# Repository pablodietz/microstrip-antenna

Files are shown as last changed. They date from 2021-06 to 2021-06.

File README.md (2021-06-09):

<p align="center">
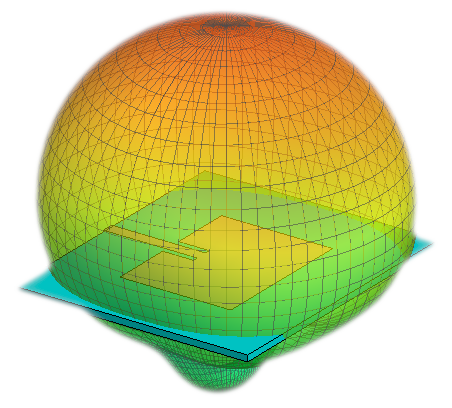
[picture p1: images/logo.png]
  
</p>

# Microstrip Antenna
Design and implementation of microstrip antenna. The idea is to improve the connectivity of a home WIFI link for G and N standards.

## Specs

* Resonance Frequency (fr): 2.422 GHz
* SWR < 2 with BW > 44 MHz
* Directivity > 3dB

## Substrate

* Material: FR4
* Substrate height (h): 1.6 mm
* Relative dielectric constant of substrate: 4.5
* Loss tangent: 0.0025

## Dimensions

<p align="center">
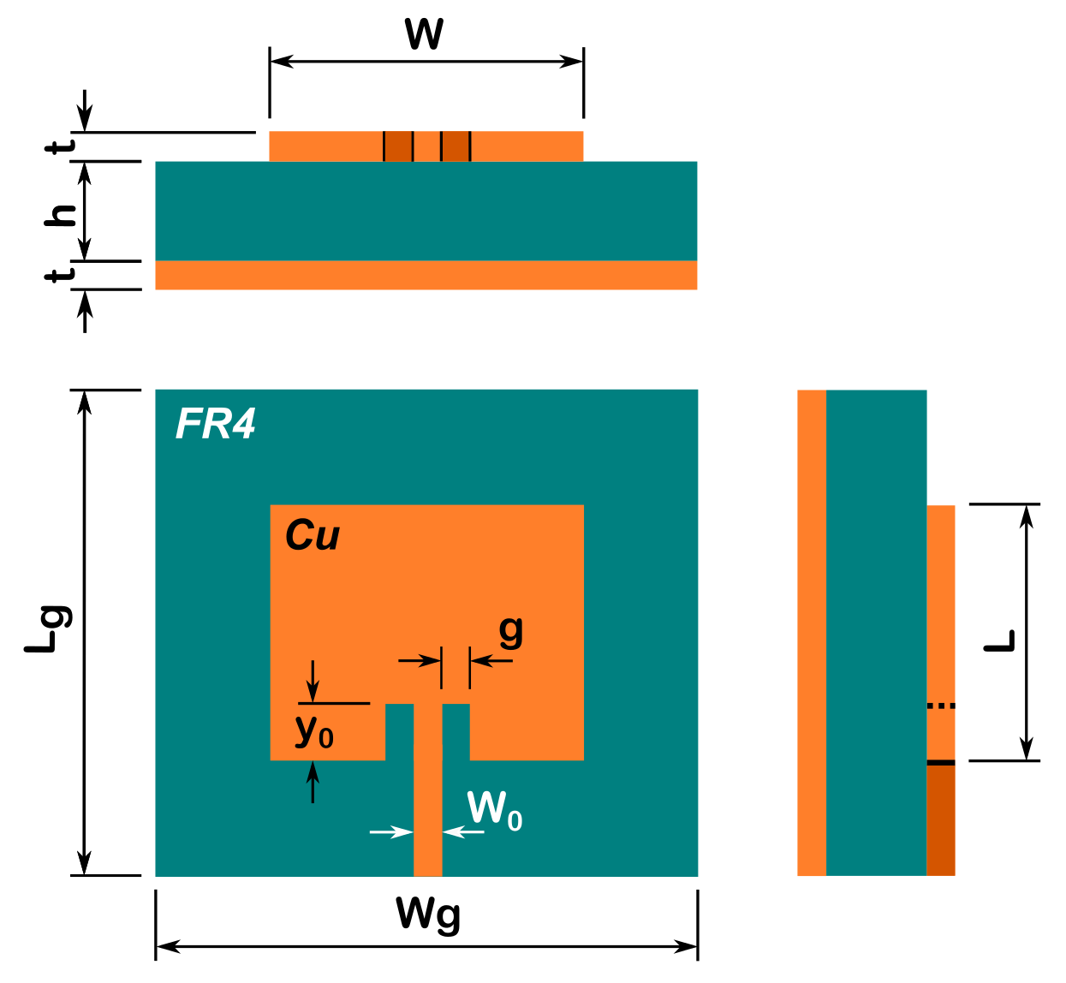
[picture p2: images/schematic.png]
  
</p>

<table align="center">
  <tr>
    <th align="center">Dimension</th>
    <th align="center">Value</th>
    <th align="center">Unit</th>
  </tr>
  <tr>
    <td align="center">t</td>
    <td align="center">35</td>
    <td align="center">µm</td>
  </tr>
  <tr>
    <td align="center">h</td>
    <td align="center">1.6</td>
    <td align="center">mm</td>
  </tr>
  <tr>
    <td align="center">W</td>
    <td align="center">37.35</td>
    <td align="center">mm</td>
  </tr>
  <tr>
    <td align="center">L</td>
    <td align="center">28.55</td>
    <td align="center">mm</td>
  </tr>
  <tr>
    <td align="center">Wg</td>
    <td align="center">70</td>
    <td align="center">mm</td>
  </tr>
  <tr>
    <td align="center">Lg</td>
    <td align="center">60</td>
    <td align="center">mm</td>
  </tr>
  <tr>
    <td align="center">W0</td>
    <td align="center">3.05</td>
    <td align="center">mm</td>
  </tr>
  <tr>
    <td align="center">g</td>
    <td align="center">1.4</td>
    <td align="center">mm</td>
  </tr>
  <tr>
    <td align="center">y0</td>
    <td align="center">7.94</td>
    <td align="center">mm</td>
  </tr>
</table>

## Layout and Finished Antenna

<p align="center">
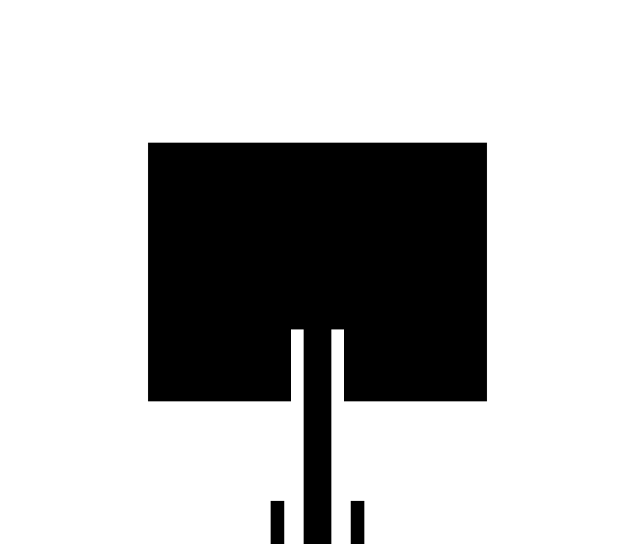
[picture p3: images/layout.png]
  
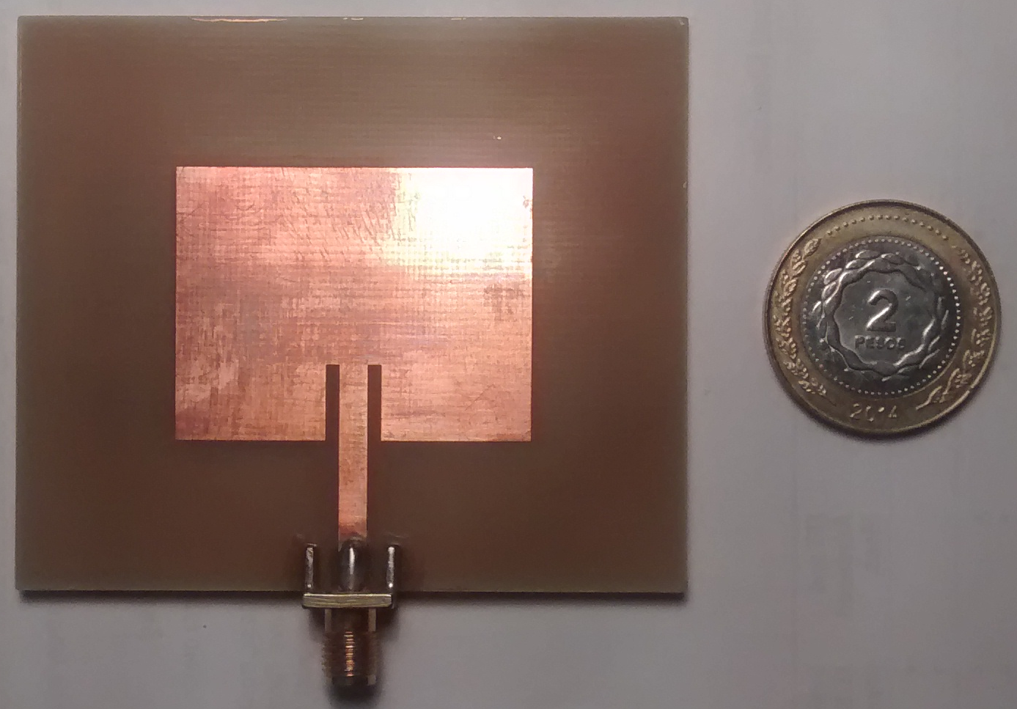
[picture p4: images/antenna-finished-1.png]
  
</p>

## Radiation Pattern: E and H Planes

The polarization of the microstrip antenna is linear such that the electric field vector is contained in the E-Plane and the magnetic field vector is contained in the H-Plane. It is observed that the type of power chosen considerably disturbs the radiation pattern of the antenna in E-Plane.

<p align="center">
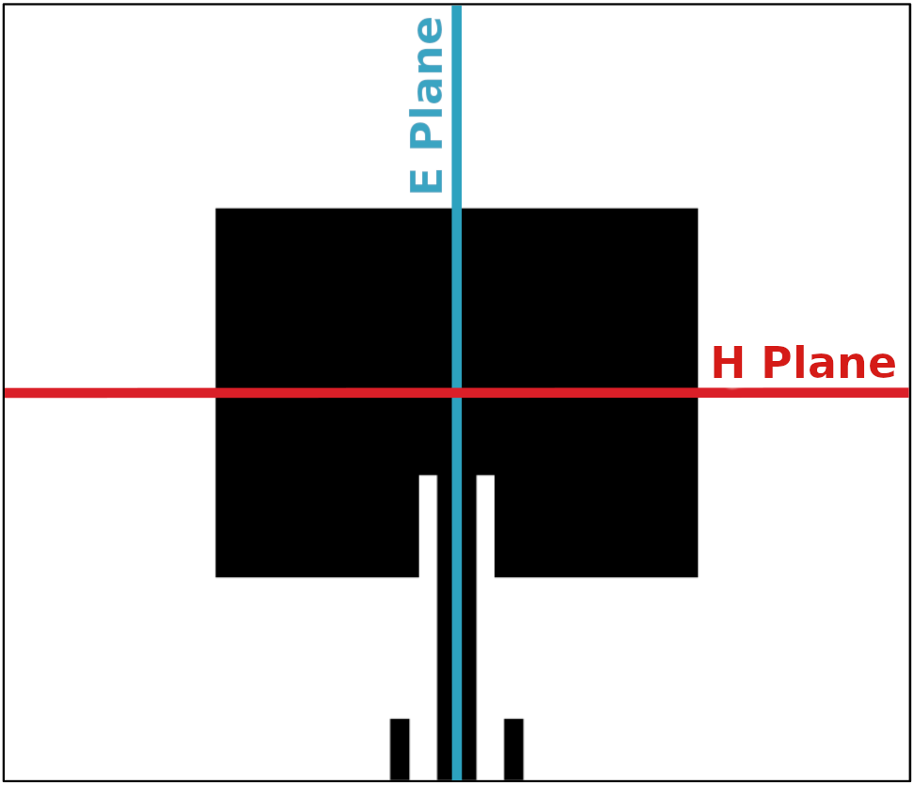
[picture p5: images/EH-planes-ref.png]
  
</p>

The results of measurements and simulations are shown below.

<table align="center">
    <tr>
      <th align="center">H-Plane</th>
      <th align="center">E-Plane</th>
    </tr>
    <tr>
      <th align="center">
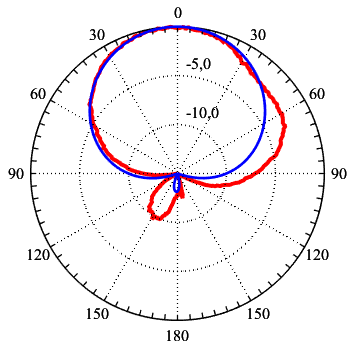
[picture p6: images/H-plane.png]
        
      </th>
      <th align="center">
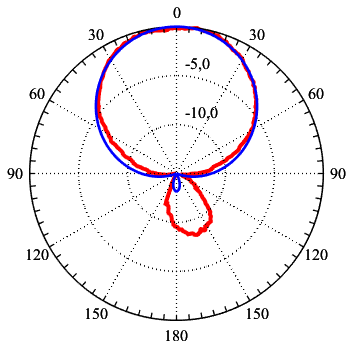
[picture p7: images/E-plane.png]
        
      </th>
    </tr>
    <tr>
      <td align="left">
        Simulation:
        <ul>
          <li>G @ 2.4220 GHz = 3.8 dB</li>
          <li>SLL @ 2.4220 GHz = 16 dB</li>
          <li>Δθ -3dB @ 2.4220 GHz = 82°</li>
        </ul>
        Measurement:
        <ul>
          <li>SLL @ 2.4824 GHz = 6.8 dB</li>
          <li>Δθ(-3dB) @ 2.4220 GHz = 82°</li>
        </ul>
      </td>
      <td align="left">
        Simulation:        
        <ul>
          <li>G @ 2.4220 GHz = 3.8 dB</li>
          <li>SLL @ 2.4220 GHz = 16 dB</li>
          <li>Δθ(-3dB) @ 2.4220 GHz = 93°</li>
        </ul>
        Measurement:
        <ul>
          <li>SLL @ 2.4824 GHz = 10 dB</li>
          <li>Δθ -3dB @ 2.4220 GHz = 105°</li>
        </ul>
      </td>
    </tr>
</table>

## 3D Radiation Pattern

<p align="center">
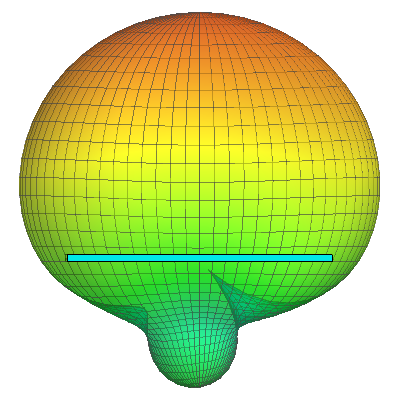
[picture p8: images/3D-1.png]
  
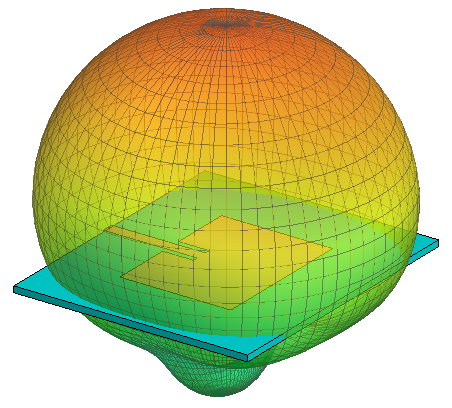
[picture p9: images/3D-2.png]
  
</p>

## References
* C. A. Balanis, Antenna Theory: Analysis and Design, Third Edition, Wiley-Interscience, 2005.
* Warren L. Stutzman, Gary A. Thiele, Antenna Theory and Design, Third Edition, Wiley-Interscience, 2013.

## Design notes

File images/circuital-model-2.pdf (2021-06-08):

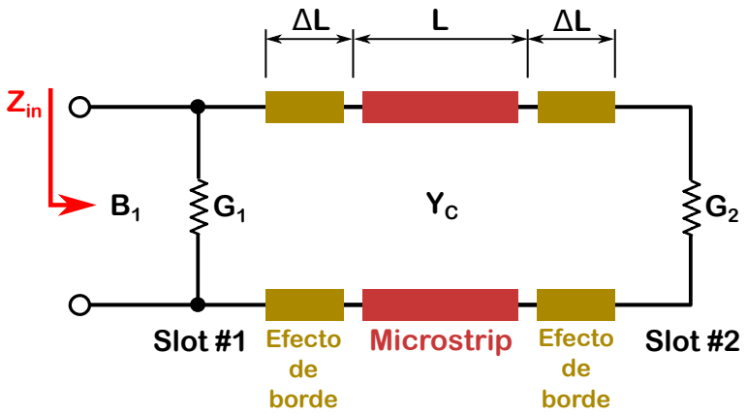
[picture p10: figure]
Zin; Slot #1 Efecto Microstrip; Slot #2; de borde; Efecto de borde

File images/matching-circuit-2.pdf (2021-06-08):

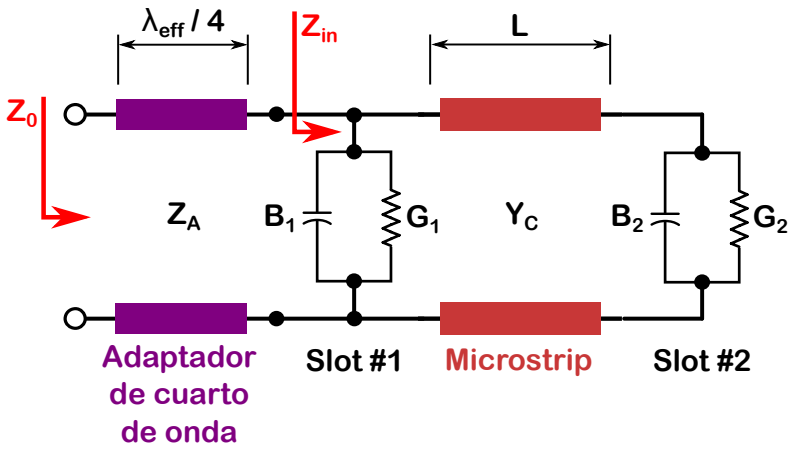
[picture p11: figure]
Zin; Adaptador de cuarto de onda; Slot #1 Microstrip; Slot #2; λeff / 4

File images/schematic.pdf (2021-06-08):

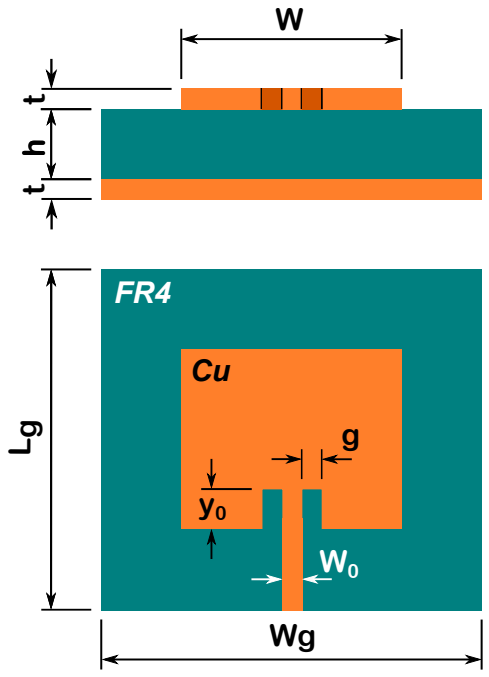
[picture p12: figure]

L

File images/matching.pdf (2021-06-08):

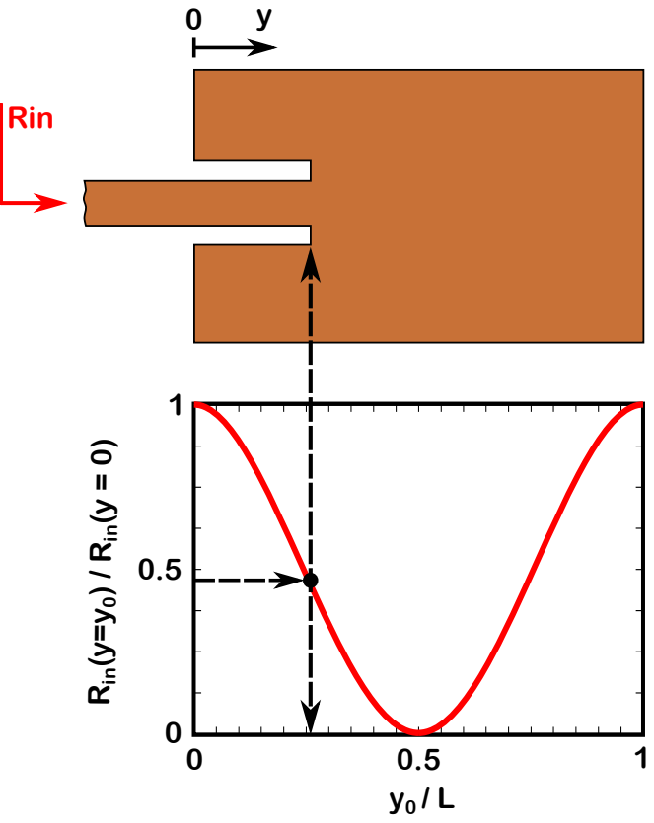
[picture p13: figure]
Rin(y=y0) / Rin(y = 0); Rin

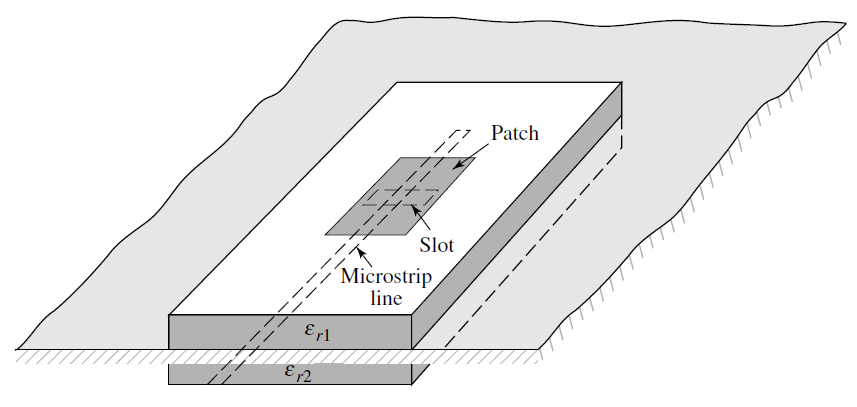
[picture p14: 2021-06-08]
images/feeding-2.png

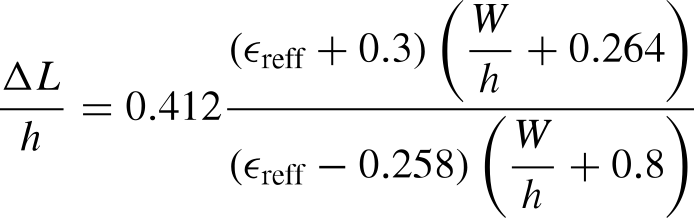
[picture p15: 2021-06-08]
images/deltal-formula.png

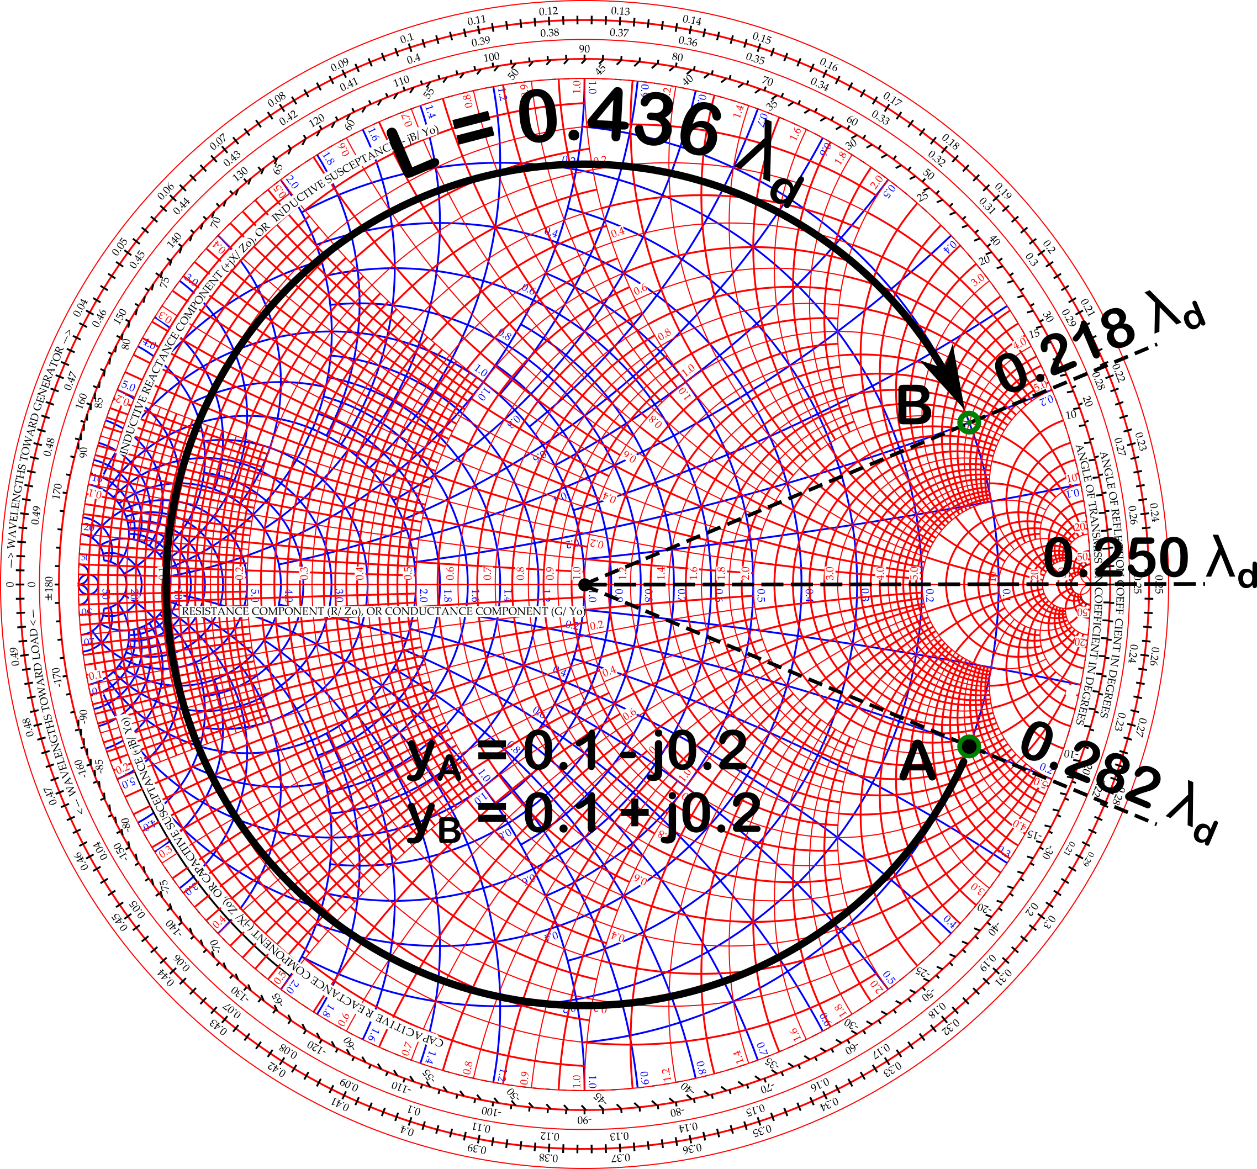
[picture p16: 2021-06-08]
images/smith-model-2.png

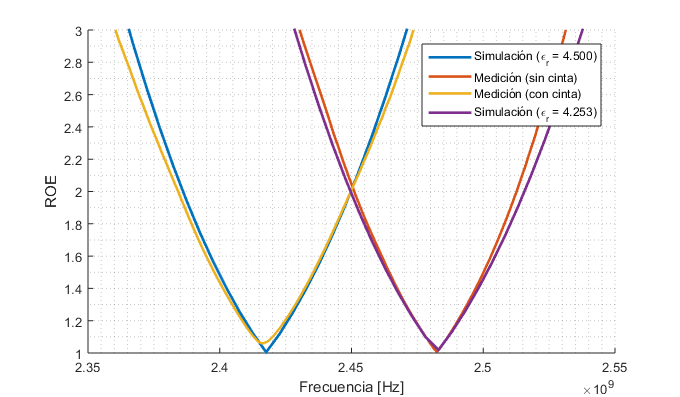
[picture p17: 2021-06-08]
images/roe.png

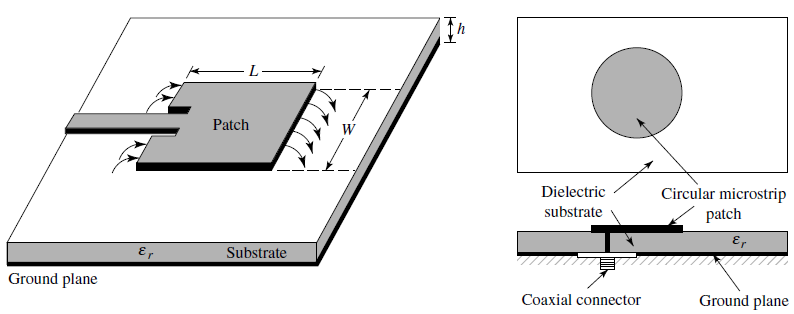
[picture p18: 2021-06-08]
images/feeding-1.png

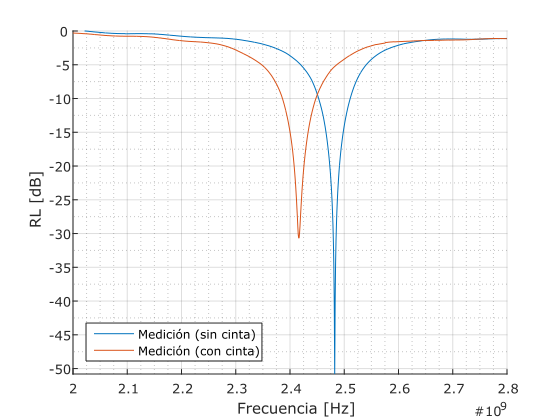
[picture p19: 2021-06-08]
images/rl-7.png

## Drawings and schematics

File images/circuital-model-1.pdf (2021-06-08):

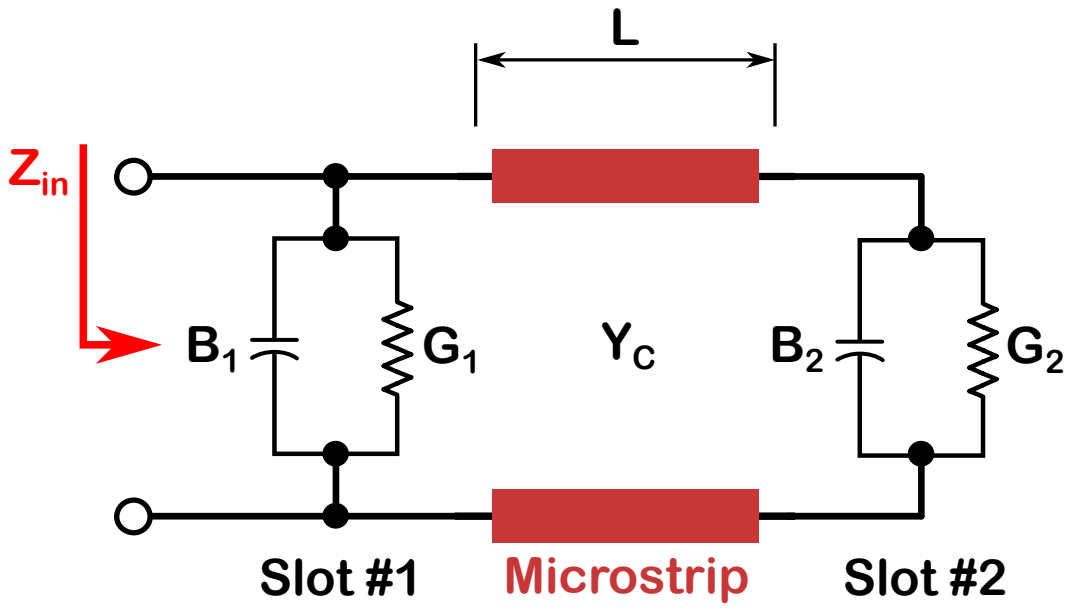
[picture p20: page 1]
Zin; Slot #1; Microstrip; Slot #2

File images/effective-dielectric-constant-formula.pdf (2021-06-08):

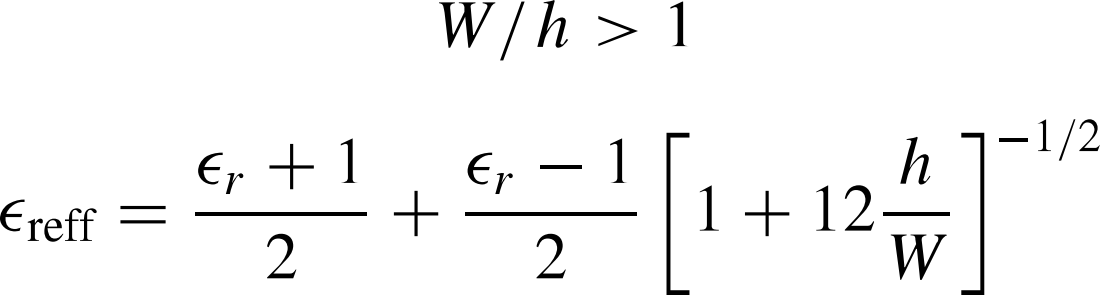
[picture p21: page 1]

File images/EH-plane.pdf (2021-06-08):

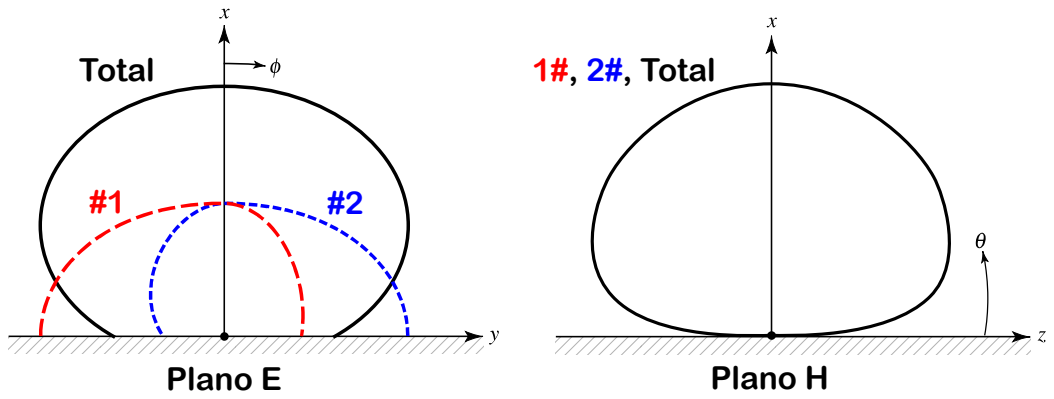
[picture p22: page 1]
Plano E; Plano H; Total; 1#, 2#, Total

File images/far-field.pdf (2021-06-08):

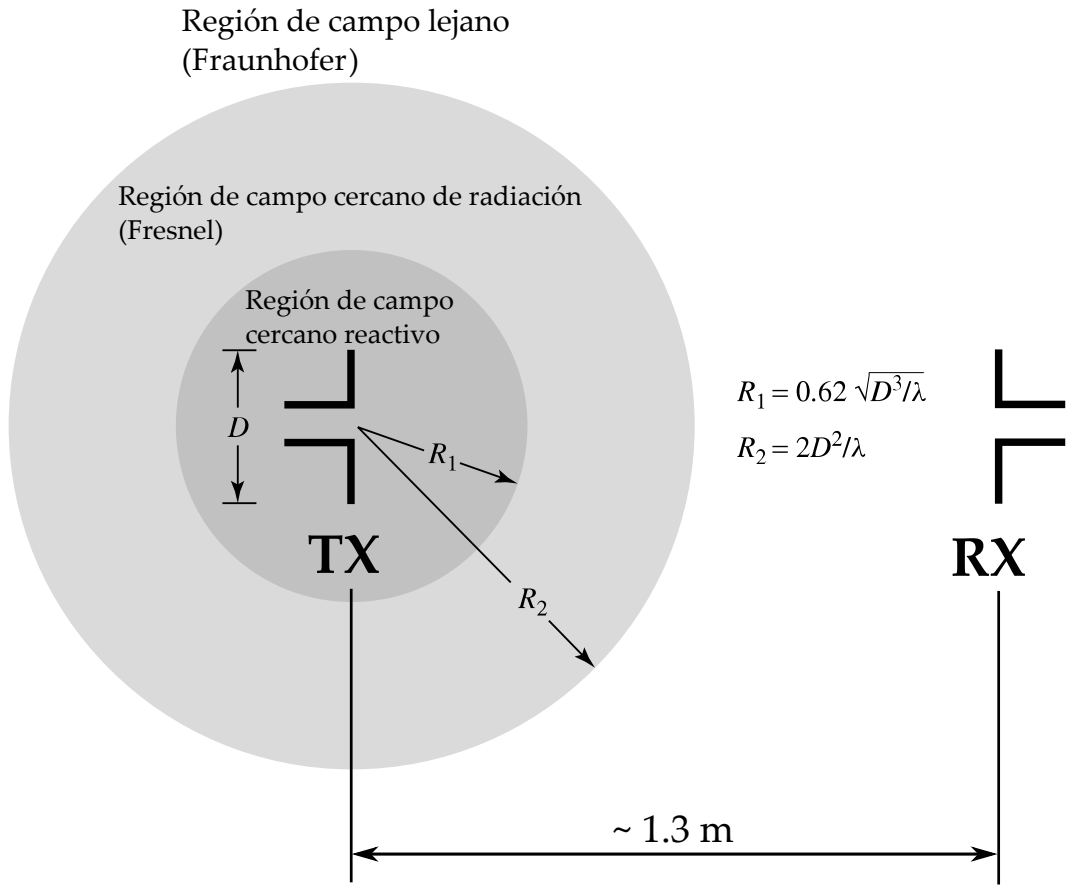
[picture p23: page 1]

Región de campo lejano
(Fraunhofer)

Región de campo cercano de radiación
(Fresnel)

Región de campo
cercano reactivo

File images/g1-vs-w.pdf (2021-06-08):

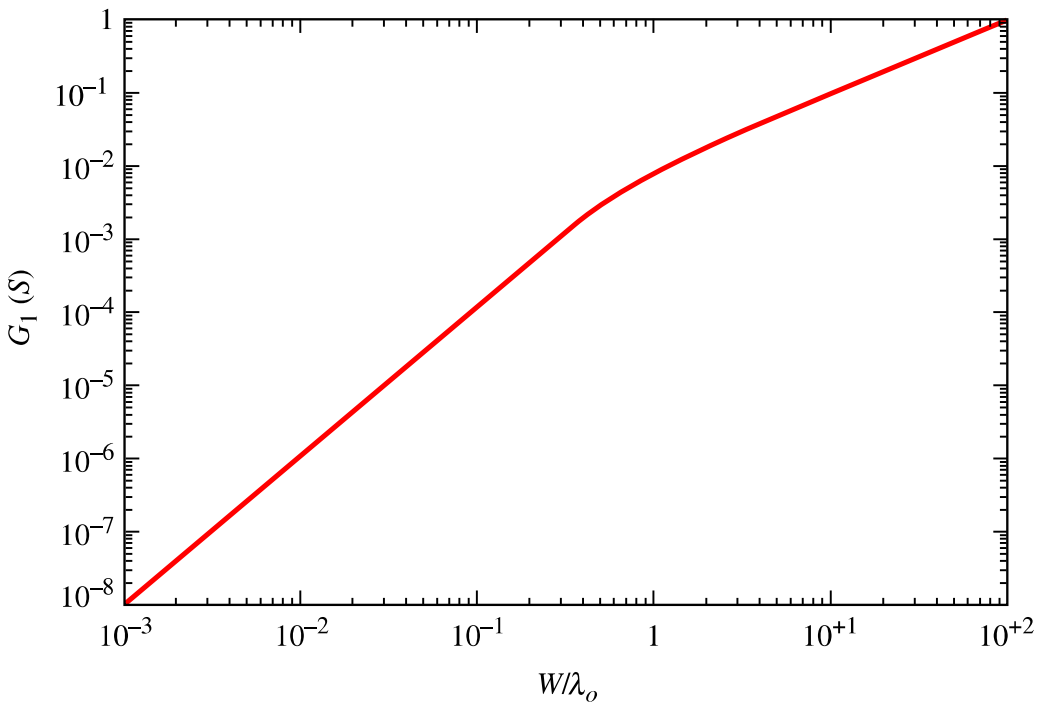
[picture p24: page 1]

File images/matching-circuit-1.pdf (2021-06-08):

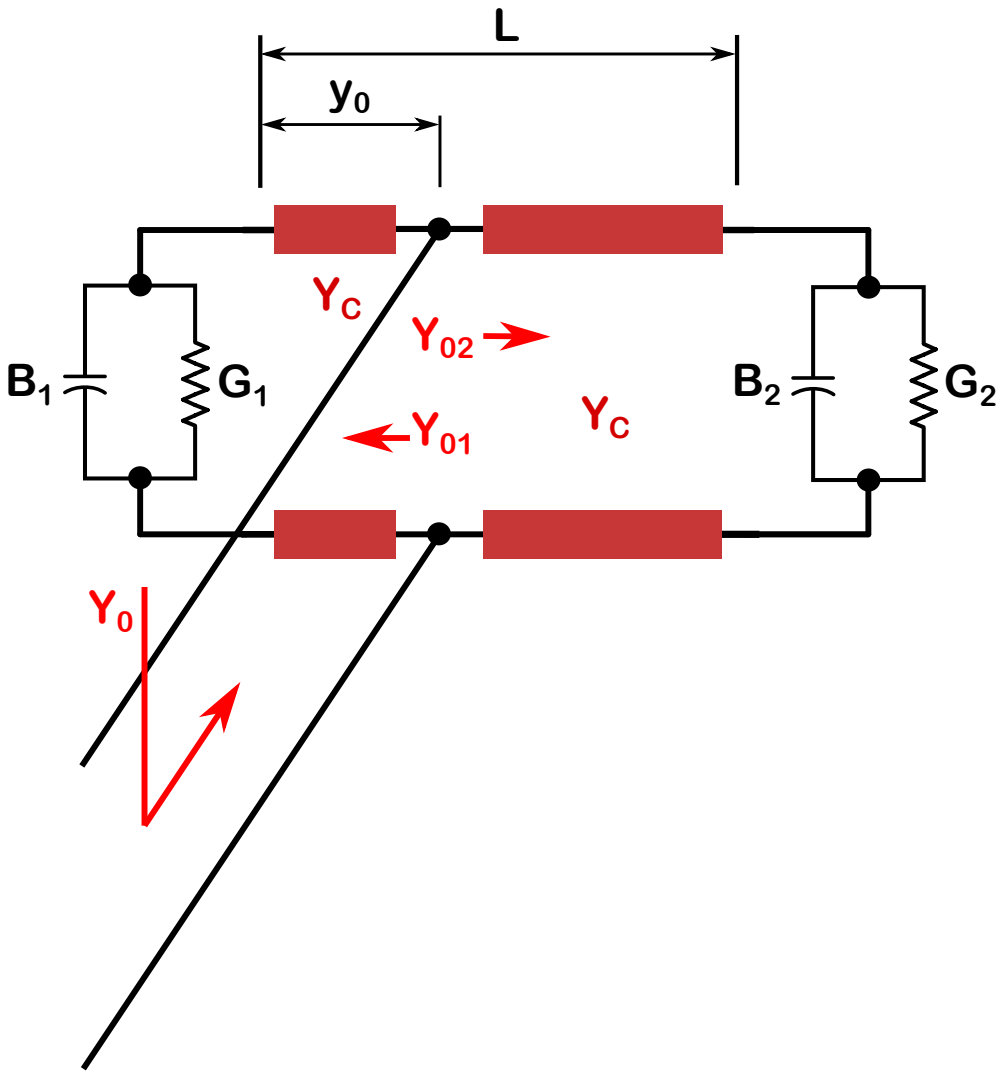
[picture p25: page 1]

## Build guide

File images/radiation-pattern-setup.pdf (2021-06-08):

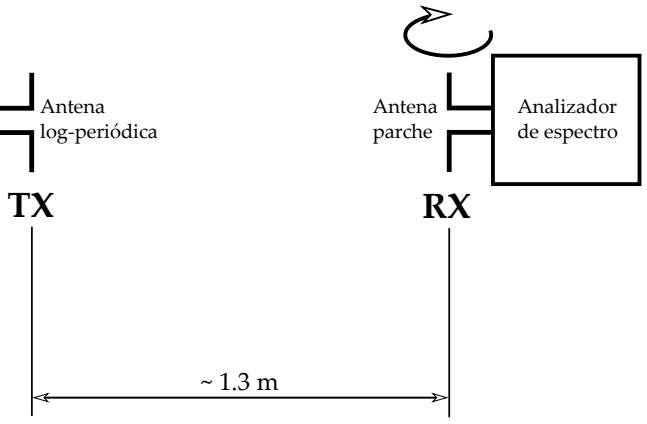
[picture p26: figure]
Analizador de espectro; Antena log-periódica; Antena parche

Generador
de RF

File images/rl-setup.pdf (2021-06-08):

Analizador
de redes
vectorial

Antena
parche

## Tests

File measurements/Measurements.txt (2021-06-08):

		PerLog		Patch
	A	Y		Y
	|	|		|
	|	|		|
   1.8m	|	|		|
	|	|		|
	|	|		|
	v	|		|

			1.5m
		 <------------->

f0 = 2.4832 GHz
